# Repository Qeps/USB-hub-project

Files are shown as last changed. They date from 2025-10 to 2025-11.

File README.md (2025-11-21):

# PCB Design
Four-layer PCB project expanding two USB ports from a computer into eight downstream ports.
Designed in KiCad, conceptually based on the CircuitDigest (Original project: https://circuitdigest.com/electronic-circuits/diy-hub-port-extender) project, but extended to support two independent USB hub controllers.

Base Project (CircuitDigest)
- Uses the GL850G USB 2.0 hub controller
- Expands one USB port into four downstream ports
- Powered directly from 5 V USB input
- The controller integrates internal 3.3 V and 1.8 V regulators, no external LDO required
- Basic passive components: resistors and decoupling capacitors
- USB-A connectors for downstream ports and one upstream connector
- Includes ESD protection (TVS diodes) for both upstream and downstream ports

Extended Version (this project)
- Two upstream USB inputs expanded to eight downstream ports (two hub controllers)
- Implemented on a 4-layer PCB for improved power and signal routing
- Thickened power traces for stable 5 V distribution across all ports
- Matched USB data line lengths to maintain signal integrity and timing
- Guard ring added around USB signal area to improve EMI and ESD immunity
- Independent hub sections sharing common 5 V supply and ground planes

KiCAD schematic:



KiCAD 3D board view:
ProjektUSBHUB

# Prototype Board
This project is currently under development and PCBWay provided the prototype boards as part of a collaboration. The PCBs arrived with consistent manufacturing quality: clean routing, correct layer alignment, and accurate silkscreen. 

The ordering workflow was straightforward. Uploading the Gerber files and selecting the manufacturing parameters was clear enough that the whole process stayed focused on the technical aspects of the design.

Photo of the prototypes:


Having the boards early in the process accelerates testing and helps refine the next revision.
Here you can order your board: https://www.pcbway.com/

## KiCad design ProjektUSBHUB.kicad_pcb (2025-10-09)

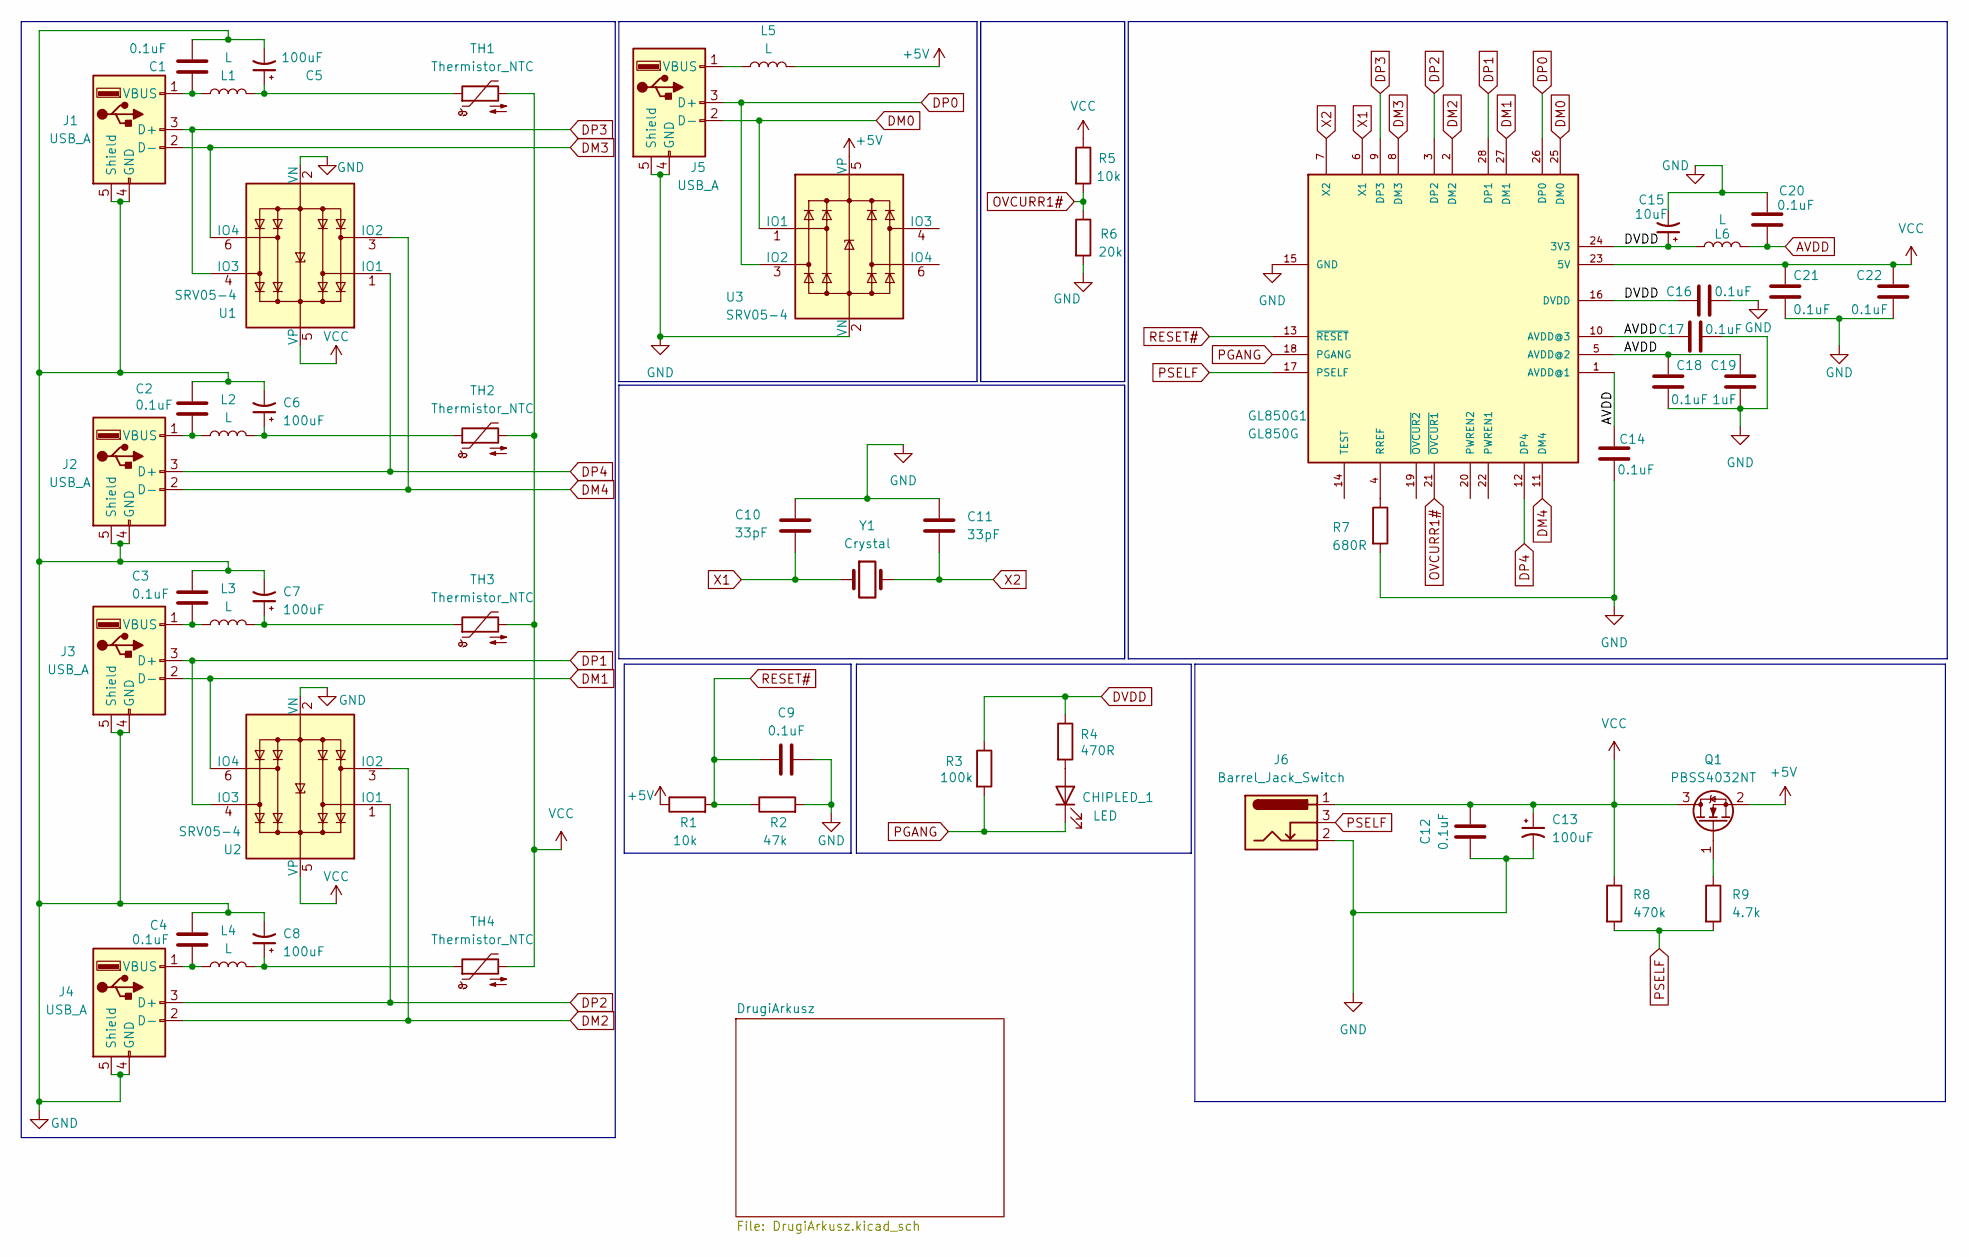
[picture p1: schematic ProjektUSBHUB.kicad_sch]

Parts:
C1, C2, C3, C4, C9, C12, C14, C16, C17, C18, C20, C21, C22: 0.1uF; C_0603_1608Metric_Pad1.08x0.95mm_HandSolder
C5, C6, C7, C8, C13: 100uF; C_Radial_D6.3mm_H11.0mm_P2.50mm
C10, C11: 33pF; C_0603_1608Metric_Pad1.08x0.95mm_HandSolder
C15: 10uF; C_Radial_D6.3mm_H11.0mm_P2.50mm
C19: 1uF; C_0603_1608Metric_Pad1.08x0.95mm_HandSolder
CHIPLED_1: LED; D_0805_2012Metric_Pad1.15x1.40mm_HandSolder
GL850G1: GL850G; SSOP28_GL850G_GEN-L
J1, J2, J3, J4, J5: USB_A; USB_A_TE_292303-7_Horizontal
J6: Barrel_Jack_Switch; PJ-102AH
L1, L2, L3, L4, L5, L6: L; L_0603_1608Metric_Pad1.05x0.95mm_HandSolder
Q1: PBSS4032NT; SOT-23
R1, R5: 10k; R_0603_1608Metric_Pad0.98x0.95mm_HandSolder
R2: 47k; R_0603_1608Metric_Pad0.98x0.95mm_HandSolder
R3: 100k; R_0603_1608Metric_Pad0.98x0.95mm_HandSolder
R4: 470R; R_0603_1608Metric_Pad0.98x0.95mm_HandSolder
R6: 20k; R_0603_1608Metric_Pad0.98x0.95mm_HandSolder
R7: 680R; R_0603_1608Metric_Pad0.98x0.95mm_HandSolder
R8: 470k; R_0603_1608Metric_Pad0.98x0.95mm_HandSolder
R9: 4.7k; R_0603_1608Metric_Pad0.98x0.95mm_HandSolder
TH1, TH2, TH3, TH4: Thermistor_NTC; R_0805_2012Metric_Pad1.20x1.40mm_HandSolder
U1, U2, U3: SRV05-4; TSOT-23-6_HandSoldering
Y1: Crystal; Crystal_SMD_ECS_CSM3X-2Pin_7.6x4.1mm

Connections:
+5V: L5.2, Q1.2 (S), R1.1, U3.5 (VP); also elsewhere on the board
AVDD: C14.1, C17.1, C18.1, C19.1, C20.2, GL850G1.1 (AVDD@1), GL850G1.5 (AVDD@2), GL850G1.10 (AVDD@3), L6.2
DM0: GL850G1.25 (DM0), J5.2 (D-), U3.1 (IO1)
DM1: GL850G1.27 (DM1), J3.2 (D-), U2.6 (IO4)
DM2: GL850G1.2 (DM2), J4.2 (D-), U2.3 (IO2)
DM3: GL850G1.8 (DM3), J1.2 (D-), U1.6 (IO4)
DM4: GL850G1.11 (DM4), J2.2 (D-), U1.3 (IO2)
DP0: GL850G1.26 (DP0), J5.3 (D+), U3.3 (IO2)
DP1: GL850G1.28 (DP1), J3.3 (D+), U2.4 (IO3)
DP2: GL850G1.3 (DP2), J4.3 (D+), U2.1 (IO1)
DP3: GL850G1.9 (DP3), J1.3 (D+), U1.4 (IO3)
DP4: GL850G1.12 (DP4), J2.3 (D+), U1.1 (IO1)
DVDD: C15.1, C16.1, GL850G1.16 (DVDD), GL850G1.24 (3V3), L6.1, R3.1, R4.1
GND: C1.2, C2.1, C3.1, C4.1, C5.2, C6.2, C7.2, C8.2, C9.2, C10.1, C11.1, C12.1, C13.2, C14.2, C15.2, C16.2, C17.2, C18.2, C19.2, C20.1, C21.2, C22.2, GL850G1.15 (GND), J1.4 (GND), J1.5 (Shield), J2.4 (GND), J2.5 (Shield), J3.4 (GND), J3.5 (Shield), J4.4 (GND), J4.5 (Shield), J5.4 (GND), J5.5 (Shield), J6.2, R2.2, R6.2, R7.2, U1.2 (VN), U2.2 (VN), U3.2 (VN); also elsewhere on the board
unnamed: C5.1, L1.2, TH1.1
unnamed: C6.1, L2.2, TH2.1
unnamed: C7.1, L3.2, TH3.1
unnamed: C8.1, L4.2, TH4.1
unnamed: CHIPLED_1.2 (A), R4.2
unnamed: GL850G1.4 (RREF), R7.1
unnamed: C1.1, J1.1 (VBUS), L1.1
unnamed: C2.2, J2.1 (VBUS), L2.1
unnamed: C3.2, J3.1 (VBUS), L3.1
unnamed: C4.2, J4.1 (VBUS), L4.1
unnamed: J5.1 (VBUS), L5.1
unnamed: Q1.1 (G), R9.1
OVCURR1#: GL850G1.21 (~OVCUR1), R5.2, R6.1
PGANG: CHIPLED_1.1 (K), GL850G1.18 (PGANG), R3.2
PSELF: GL850G1.17 (PSELF), J6.3, R8.2, R9.2; also elsewhere on the board
RESET#: C9.1, GL850G1.13 (~RESET), R1.2, R2.1
VCC: C12.2, C13.1, C21.1, C22.1, GL850G1.23 (5V), J6.1, Q1.3 (D), R5.1, R8.1, TH1.2, TH2.2, TH3.2, TH4.2, U1.5 (VP), U2.5 (VP); also elsewhere on the board
X1: C10.2, GL850G1.6 (X1), Y1.1
X2: C11.2, GL850G1.7 (X2), Y1.2

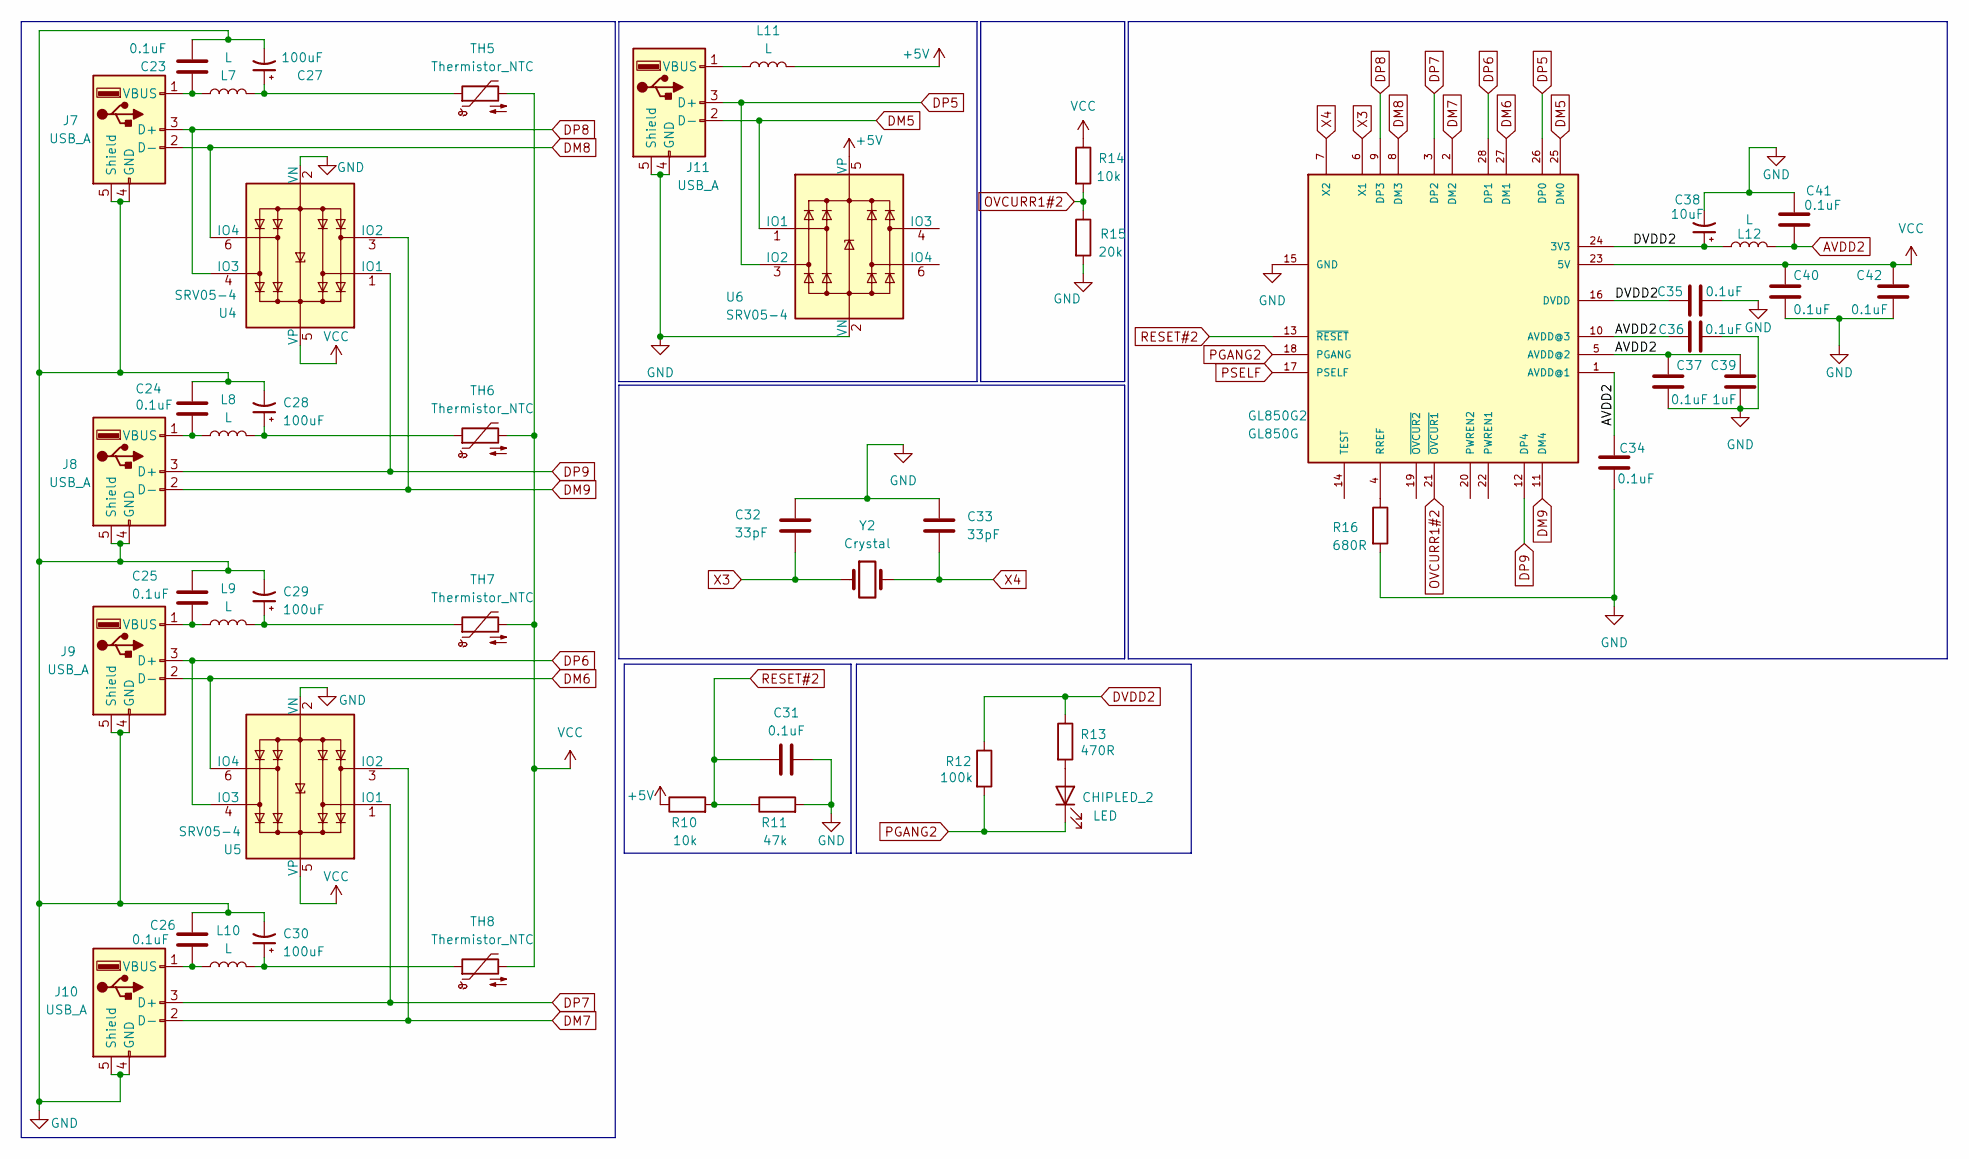
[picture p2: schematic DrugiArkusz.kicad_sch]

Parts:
C23, C24, C25, C26, C31, C34, C35, C36, C37, C40, C41, C42: 0.1uF; C_0603_1608Metric_Pad1.08x0.95mm_HandSolder
C27, C28, C29, C30: 100uF; C_Radial_D6.3mm_H11.0mm_P2.50mm
C32, C33: 33pF; C_0603_1608Metric_Pad1.08x0.95mm_HandSolder
C38: 10uF; C_Radial_D6.3mm_H11.0mm_P2.50mm
C39: 1uF; C_0603_1608Metric_Pad1.08x0.95mm_HandSolder
CHIPLED_2: LED; D_0805_2012Metric_Pad1.15x1.40mm_HandSolder
GL850G2: GL850G; SSOP28_GL850G_GEN-L
J7, J8, J9, J10, J11: USB_A; USB_A_TE_292303-7_Horizontal
L7, L8, L9, L10, L11, L12: L; L_0603_1608Metric_Pad1.05x0.95mm_HandSolder
R10, R14: 10k; R_0603_1608Metric_Pad0.98x0.95mm_HandSolder
R11: 47k; R_0603_1608Metric_Pad0.98x0.95mm_HandSolder
R12: 100k; R_0603_1608Metric_Pad0.98x0.95mm_HandSolder
R13: 470R; R_0603_1608Metric_Pad0.98x0.95mm_HandSolder
R15: 20k; R_0603_1608Metric_Pad0.98x0.95mm_HandSolder
R16: 680R; R_0603_1608Metric_Pad0.98x0.95mm_HandSolder
TH5, TH6, TH7, TH8: Thermistor_NTC; R_0805_2012Metric_Pad1.20x1.40mm_HandSolder
U4, U5, U6: SRV05-4; TSOT-23-6_HandSoldering
Y2: Crystal; Crystal_SMD_ECS_CSM3X-2Pin_7.6x4.1mm

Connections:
+5V: L11.2, R10.1, U6.5 (VP); also elsewhere on the board
AVDD2: C34.1, C36.1, C37.1, C39.1, C41.2, GL850G2.1 (AVDD@1), GL850G2.5 (AVDD@2), GL850G2.10 (AVDD@3), L12.2
DM5: GL850G2.25 (DM0), J11.2 (D-), U6.1 (IO1)
DM6: GL850G2.27 (DM1), J9.2 (D-), U5.6 (IO4)
DM7: GL850G2.2 (DM2), J10.2 (D-), U5.3 (IO2)
DM8: GL850G2.8 (DM3), J7.2 (D-), U4.6 (IO4)
DM9: GL850G2.11 (DM4), J8.2 (D-), U4.3 (IO2)
DP5: GL850G2.26 (DP0), J11.3 (D+), U6.3 (IO2)
DP6: GL850G2.28 (DP1), J9.3 (D+), U5.4 (IO3)
DP7: GL850G2.3 (DP2), J10.3 (D+), U5.1 (IO1)
DP8: GL850G2.9 (DP3), J7.3 (D+), U4.4 (IO3)
DP9: GL850G2.12 (DP4), J8.3 (D+), U4.1 (IO1)
DVDD2: C35.1, C38.1, GL850G2.16 (DVDD), GL850G2.24 (3V3), L12.1, R12.1, R13.1
GND: C23.2, C24.1, C25.1, C26.1, C27.2, C28.2, C29.2, C30.2, C31.2, C32.1, C33.1, C34.2, C35.2, C36.2, C37.2, C38.2, C39.2, C40.2, C41.1, C42.2, GL850G2.15 (GND), J7.4 (GND), J7.5 (Shield), J8.4 (GND), J8.5 (Shield), J9.4 (GND), J9.5 (Shield), J10.4 (GND), J10.5 (Shield), J11.4 (GND), J11.5 (Shield), R11.2, R15.2, R16.2, U4.2 (VN), U5.2 (VN), U6.2 (VN); also elsewhere on the board
unnamed: C27.1, L7.2, TH5.1
unnamed: C28.1, L8.2, TH6.1
unnamed: C29.1, L9.2, TH7.1
unnamed: C30.1, L10.2, TH8.1
unnamed: CHIPLED_2.2 (A), R13.2
unnamed: GL850G2.4 (RREF), R16.1
unnamed: C23.1, J7.1 (VBUS), L7.1
unnamed: C24.2, J8.1 (VBUS), L8.1
unnamed: C25.2, J9.1 (VBUS), L9.1
unnamed: C26.2, J10.1 (VBUS), L10.1
unnamed: J11.1 (VBUS), L11.1
OVCURR1#2: GL850G2.21 (~OVCUR1), R14.2, R15.1
PGANG2: CHIPLED_2.1 (K), GL850G2.18 (PGANG), R12.2
PSELF: GL850G2.17 (PSELF); also elsewhere on the board
RESET#2: C31.1, GL850G2.13 (~RESET), R10.2, R11.1
VCC: C40.1, C42.1, GL850G2.23 (5V), R14.1, TH5.2, TH6.2, TH7.2, TH8.2, U4.5 (VP), U5.5 (VP); also elsewhere on the board
X3: C32.2, GL850G2.6 (X1), Y2.1
X4: C33.2, GL850G2.7 (X2), Y2.2

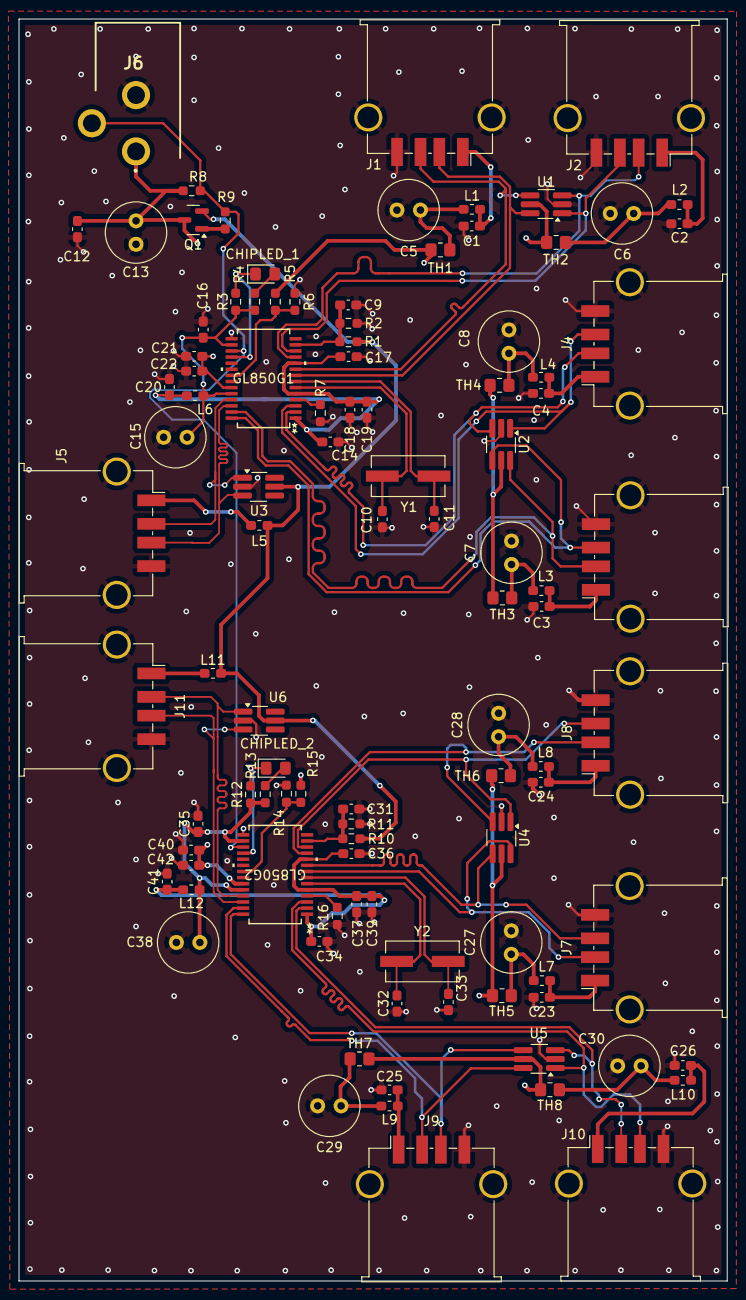
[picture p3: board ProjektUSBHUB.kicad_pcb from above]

Board: 4 copper layers, 75.4 x 134.4 mm, 102 parts (0 on the bottom side), 61 nets.

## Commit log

2025-10-09 PCB design
    [DrugiArkusz.kicad_sch, ProjektUSBHUB.kicad_pcb, ProjektUSBHUB.kicad_sch]
2025-11-21 Update README.md
    Added a section about the prototype board development and collaboration with PCBWay.
2025-11-21 Update README.md
    Added ordering link for the board.
